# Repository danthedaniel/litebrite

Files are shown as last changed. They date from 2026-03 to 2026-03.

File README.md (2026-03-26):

# litebrite

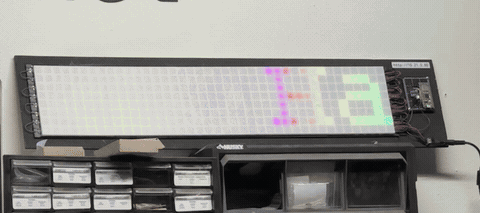
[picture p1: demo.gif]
Demo


## Hardware

- **Board**: Raspberry Pi Pico 2W (RP2350, Wi-Fi/BLE capable)
- **Display**: 40x8 WS2812B (NeoPixel) LED matrix (320 LEDs total)
- **Data pin**: GP20
- **Wiring**: Serpentine layout — even rows run right-to-left, odd rows left-to-right
- **Coordinate system**: x=0 is left, y=0 is bottom

## Firmware

The board runs **MicroPython**. All code must be compatible with MicroPython (not CPython).

Key differences from CPython:
- Use `machine.Pin`, `neopixel.NeoPixel`, `time.sleep_ms()` etc.
- No `pip` — only built-in modules and files copied to the board
- Limited RAM — keep data structures small and avoid large allocations

## Setup

```bash
# Installs type stubs for editor/IDE support
# Installs mpremote
make setup
```

Requires [uv](https://docs.astral.sh/uv/). Installs MicroPython type stubs into `typings/` for use with basedpyright/pylance, and installs `mpremote` for deploying to the board.

## Flashing MicroPython firmware

1. Hold BOOTSEL while plugging in the Pico — it mounts as a USB drive
2. Download the MicroPython `.uf2` for **Pico 2W** from https://micropython.org/download/RPI_PICO2_W/
3. Drag the `.uf2` onto the mounted drive — board reboots into MicroPython

## Deploying Code

```bash
make deploy
```

Copies all runtime files to the board and resets it.

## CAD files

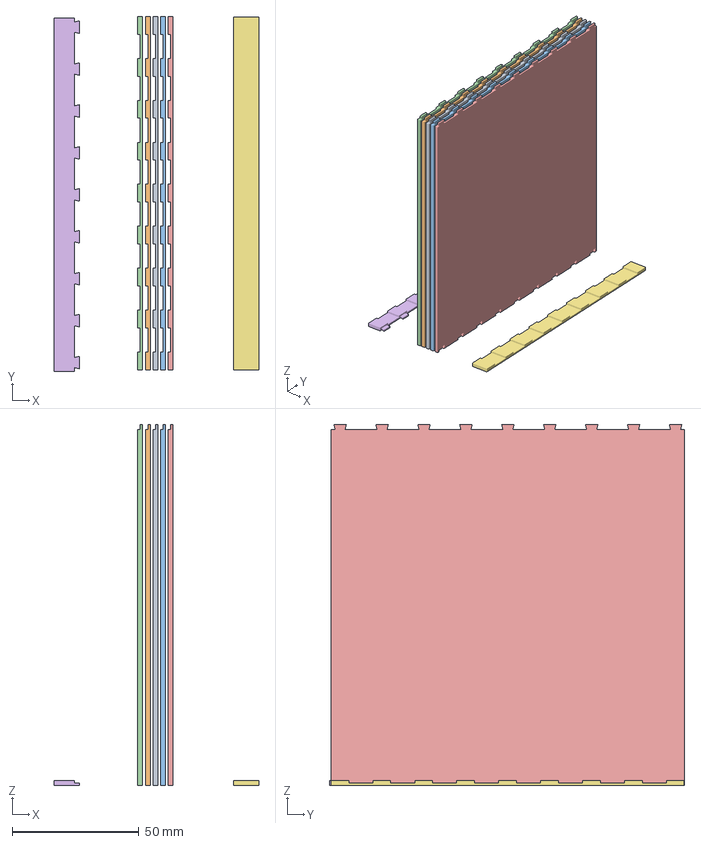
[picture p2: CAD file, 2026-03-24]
cad/led_panel.3mf
80.7 x 140.0 x 142.6 mm
led_panel.stl x 5
led_panel.stl_A
led_panel.stl_B_B

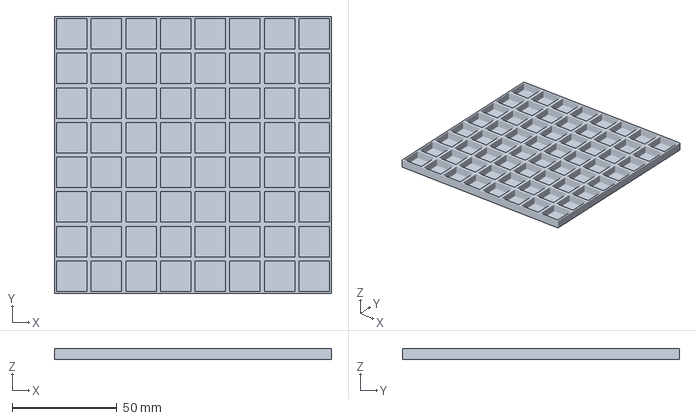
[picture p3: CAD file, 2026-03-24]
cad/led_cover.3mf
132.3 x 132.3 x 5.40 mm

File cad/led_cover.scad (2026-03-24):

overlap = 0.001;
led_size = 5;
led_spacing = 16.54;
strip_width = 10;
wall_thickness = 1;
cover_thickness = 0.4;
columns = 8;
rows = 8;

end_piece = true;

module line(row) {
    for (col = [0 : columns - 1]) {
        translate([col*led_spacing, row*led_spacing, cover_thickness])
            difference() {
                cube([led_spacing, led_spacing, 5]);
                translate([wall_thickness, wall_thickness, -overlap])
                    cube([led_spacing - 2*wall_thickness, led_spacing - 2*wall_thickness, 5 + 2*overlap]);
            };
    }
}

for (row = [0: rows - 1]) {
    difference() {
        line(row);

        if (end_piece) {
            translate([-overlap, led_spacing/2 + row*led_spacing, 8])
                rotate([0, 90, 0])
                    cylinder(1+2*overlap, 6, 6, $fn=64);
        }
    };
}

cube([columns*led_spacing, rows*led_spacing, cover_thickness+overlap]);

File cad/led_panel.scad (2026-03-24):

overlap = 0.001;
dovetail_bottom = 4;
dovetail_negative_scale = 1.02;
strip_width = 10;
led_spacing = 16.54;
panel_thickness = 2;
pixels = 8;

module dovetail(scale=1, height=panel_thickness+2*overlap) {
    length = 2 * scale;
    top = 5 * scale;
    bottom = 4 * scale;
    linear_extrude(height=height)
        polygon(points=[
            [0, 0],
            [length, (top-bottom)/2],
            [length, -(bottom + (top-bottom)/2)],
            [0, -bottom]
        ]);
}

for (i = [0 : pixels-1]) {
    translate([0, i*led_spacing, 0])
        difference() {
            cube([pixels * led_spacing, led_spacing, panel_thickness]);
            translate([-overlap, (led_spacing - strip_width + dovetail_bottom * dovetail_negative_scale) / 2, -overlap])
                dovetail(scale=dovetail_negative_scale);
        };
    
    translate([pixels * led_spacing-overlap, (led_spacing - strip_width + dovetail_bottom) / 2 + i*led_spacing, -overlap])
                dovetail(scale=1);
    
    translate([0, i*led_spacing, panel_thickness-overlap])
        cube([pixels * led_spacing, led_spacing-strip_width, panel_thickness/2]);
}

difference() {
    translate([0, pixels*led_spacing, 0])
        cube([pixels * led_spacing, led_spacing-strip_width, panel_thickness*1.5]);
    translate([-overlap, (led_spacing - strip_width + dovetail_bottom * dovetail_negative_scale) / 2 + pixels*led_spacing, -overlap])
        dovetail(scale=dovetail_negative_scale);
}

translate([pixels * led_spacing-overlap, (led_spacing - strip_width + dovetail_bottom) / 2 + pixels*led_spacing, -overlap])
    dovetail(scale=1);

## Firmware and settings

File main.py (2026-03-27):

import uasyncio
import network
import time
from font import render_text, CHAR_WIFI, CHAR_NO_WIFI
from microdot import Microdot, Request, urlencode
from screen import screen, COLS, ROWS, SCROLL_DELAY_MS
from colors import hsv_to_rgb, RGB


def rainbow_shader(x: int, _y: int, t: int) -> RGB:
    """Cycle hues across the x-axis, animated over time."""
    hue = ((x * 360) // COLS + t * 3 // 50) % 360
    return hsv_to_rgb(hue)


app = Microdot()

with open("index.html", "r") as f:
    HTML_PAGE = f.read()


@app.get('/')
async def index(_req: Request):
    return HTML_PAGE, 200, {'Content-Type': 'text/html'}


def is_hex_color(s: str) -> bool:
    return len(s) == 7 and s[0] == '#' and all(c in '0123456789abcdef' for c in s[1:])


def parse_text_payload(data: dict) -> tuple[str, bool, str]:
    text = str(data.get('text', ''))[:32]

    raw_scrolling = data.get('scrolling', False)
    if isinstance(raw_scrolling, bool):
        scrolling = raw_scrolling
    elif isinstance(raw_scrolling, str):
        scrolling = raw_scrolling.lower() == 'true'
    else:
        raise ValueError('scrolling must be a boolean or string')

    color = str(data.get('color', 'rainbow')).lower()
    if color != 'rainbow' and not is_hex_color(color):
        raise ValueError('color must be "rainbow" or a hex code like #FF0000')

    return text, scrolling, color


@app.post('/text')
async def set_text(req: Request):
    is_json = bool(req.content_type and 'application/json' in req.content_type)
    if is_json:
        data = req.json or {}
    else:
        data = req.form or {}

    try:
        text, scrolling, color = parse_text_payload(data)
    except ValueError as e:
        if is_json:
            return {'ok': False, 'error': str(e)}, 400
        else:
            return '', 303, {'Location': '/?error=' + urlencode(str(e))}

    screen.bitmap = render_text(text, "#FFFFFF" if color == "rainbow" else color)
    screen.scrolling = scrolling
    screen.shader = rainbow_shader if color == 'rainbow' else None

    if is_json:
        return {'ok': True}
    else:
        return '', 303, {'Location': '/'}


def parse_bitmap_payload(data: dict) -> list:
    raw_bitmap = data.get("bitmap")
    if not isinstance(raw_bitmap, list):
        raise ValueError('expected a list of columns')

    if len(raw_bitmap) != COLS:
        raise ValueError('bitmap must have ' + str(COLS) + ' columns')

    bitmap = []

    for x, col in enumerate(raw_bitmap):
        if not isinstance(col, list) or len(col) != ROWS:
            raise ValueError('column ' + str(x) + ' must have ' + str(ROWS) + ' pixels')

        bitmap_col = []

        for y, pixel in enumerate(col):
            if not isinstance(pixel, list) or len(pixel) != 3:
                raise ValueError('pixel at (' + str(x) + ',' + str(y) + ') must be [r, g, b]')

            for color in pixel:
                if not isinstance(color, int):
                    raise ValueError('RGB values must be integers at (' + str(x) + ',' + str(y) + ')')
                if not 0 <= color <= 255:
                    raise ValueError('RGB values must be 0-255 at (' + str(x) + ',' + str(y) + ')')

            bitmap_col.append(tuple(pixel))

        bitmap.append(bitmap_col)

    return bitmap


@app.post('/bitmap')
async def set_bitmap(req: Request):
    data = req.json or {}

    try:
        bitmap = parse_bitmap_payload(data)
    except ValueError as e:
        return {'ok': False, 'error': str(e)}, 400

    screen.bitmap = bitmap
    screen.scrolling = False
    screen.shader = None

    return {'ok': True}


async def display_loop() -> None:
    while True:
        screen.update()
        await uasyncio.sleep_ms(SCROLL_DELAY_MS)


def connect_wifi() -> str:
    wlan = network.WLAN(network.STA_IF)
    wlan.active(True)
    wlan.connect("Noisebridge", "noisebridge")
    dots = ["...", "..", ".", ".."]

    max_wait = 20
    while max_wait > 0:
        screen.show_text(CHAR_WIFI + " " + dots[max_wait % len(dots)])

        status = wlan.status()
        if status == network.STAT_GOT_IP:
            break
        if status < 0:
            screen.show_text(CHAR_NO_WIFI + " fail")
            raise RuntimeError("WiFi connection failed, status=" + str(status))

        max_wait -= 1
        time.sleep(1)

    if not wlan.isconnected():
        screen.show_text(CHAR_NO_WIFI + " fail")
        raise RuntimeError("WiFi connection timed out")

    ip = str(wlan.ifconfig()[0])
    screen.show_text(CHAR_WIFI + " :D")
    time.sleep(2)

    return ip


def main() -> None:
    screen.clear()
    ip = connect_wifi()

    bitmap = render_text(ip, "#FFFFFF")
    screen.bitmap = bitmap
    screen.scrolling = len(bitmap) > COLS

    uasyncio.create_task(display_loop())
    app.run(port=80)


def show_error(e: Exception) -> None:
    screen.bitmap = render_text("Error: " + str(e)[0:64], "#FF0000")
    screen.scrolling = True

    while True:
        screen.update()
        time.sleep_ms(SCROLL_DELAY_MS)


try:
    main()
except Exception as e:
    show_error(e)

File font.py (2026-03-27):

from colors import Bitmap, hex_to_rgb

CHAR_WIFI = '\x01'
CHAR_NO_WIFI = '\x02'

FONT = {
    ' ': [
        [0,0,0],
        [0,0,0],
        [0,0,0],
        [0,0,0],
        [0,0,0],
        [0,0,0],
        [0,0,0],
        [0,0,0],
    ],
    'A': [
        [0,0,0,1,1,0,0],
        [0,0,1,0,0,1,0],
        [0,1,0,0,0,1,0],
        [0,1,0,0,0,1,0],
        [0,1,1,1,1,1,0],
        [0,1,0,0,0,1,0],
        [1,1,1,0,1,1,1],
        [0,0,0,0,0,0,0],
    ],
    'B': [
        [1,1,1,1,0],
        [0,1,0,0,1],
        [0,1,0,0,1],
        [0,1,1,1,0],
        [0,1,0,0,1],
        [0,1,0,0,1],
        [1,1,1,1,0],
        [0,0,0,0,0],
    ],
    'C': [
        [0,0,1,1,0],
        [0,1,0,0,1],
        [1,0,0,0,1],
        [1,0,0,0,0],
        [1,0,0,0,0],
        [1,0,0,0,1],
        [0,1,1,1,0],
        [0,0,0,0,0],
    ],
    'D': [
        [1,1,1,1,0,0],
        [0,1,0,0,1,0],
        [0,1,0,0,0,1],
        [0,1,0,0,0,1],
        [0,1,0,0,0,1],
        [0,1,0,0,1,0],
        [1,1,1,1,0,0],
        [0,0,0,0,0,0],
    ],
    'E': [
        [1,1,1,1,1,1],
        [0,1,0,0,0,1],
        [0,1,0,0,0,1],
        [0,1,1,1,0,0],
        [0,1,0,0,0,0],
        [0,1,0,0,0,1],
        [1,1,1,1,1,1],
        [0,0,0,0,0,0],
    ],
    'F': [
        [1,1,1,1,1,1],
        [0,1,0,0,0,1],
        [0,1,0,0,0,1],
        [0,1,1,1,0,0],
        [0,1,0,0,0,0],
        [0,1,0,0,0,0],
        [1,1,1,0,0,0],
        [0,0,0,0,0,0],
    ],
    'G': [
        [0,0,1,1,0,0,0],
        [0,1,0,0,1,0,0],
        [1,0,0,0,0,0,0],
        [1,0,0,1,1,1,1],
        [1,0,0,0,0,1,0],
        [0,1,0,0,0,1,0],
        [0,0,1,1,1,0,0],
        [0,0,0,0,0,0,0],
    ],
    'H': [
        [1,1,1,0,1,1,1],
        [0,1,0,0,0,1,0],
        [0,1,0,0,0,1,0],
        [0,1,1,1,1,1,0],
        [0,1,0,0,0,1,0],
        [0,1,0,0,0,1,0],
        [1,1,1,0,1,1,1],
        [0,0,0,0,0,0,0],
    ],
    'I': [
        [1,1,1],
        [0,1,0],
        [0,1,0],
        [0,1,0],
        [0,1,0],
        [0,1,0],
        [1,1,1],
        [0,0,0],
    ],
    'J': [
        [0,0,0,1,1,1],
        [0,0,0,0,1,0],
        [0,0,0,0,1,0],
        [0,1,0,0,1,0],
        [1,0,0,0,1,0],
        [1,0,0,0,1,0],
        [0,1,1,1,0,0],
        [0,0,0,0,0,0],
    ],
    'K': [
        [1,1,1,0,1,1,1],
        [0,1,0,0,0,1,0],
        [0,1,0,0,1,0,0],
        [0,1,1,1,0,0,0],
        [0,1,0,0,1,0,0],
        [0,1,0,0,0,1,0],
        [1,1,1,0,1,1,1],
        [0,0,0,0,0,0,0],
    ],
    'L': [
        [1,1,1,0,0,0],
        [0,1,0,0,0,0],
        [0,1,0,0,0,0],
        [0,1,0,0,0,0],
        [0,1,0,0,0,1],
        [0,1,0,0,0,1],
        [1,1,1,1,1,1],
        [0,0,0,0,0,0],
    ],
    'M': [
        [1,1,0,0,0,0,0,1,1],
        [0,1,1,0,0,0,1,1,0],
        [0,1,0,1,0,1,0,1,0],
        [0,1,0,0,1,0,0,1,0],
        [0,1,0,0,1,0,0,1,0],
        [0,1,0,0,0,0,0,1,0],
        [1,1,1,0,0,0,1,1,1],
        [0,0,0,0,0,0,0,0,0],
    ],
    'N': [
        [1,1,0,0,1,1,1],
        [0,1,0,0,0,1,0],
        [0,1,1,0,0,1,0],
        [0,1,0,1,0,1,0],
        [0,1,0,0,1,1,0],
        [0,1,0,0,0,1,0],
        [1,1,1,0,0,1,1],
        [0,0,0,0,0,0,0],
    ],
    'O': [
        [0,0,1,1,1,0],
        [0,1,0,0,0,1],
        [1,0,0,0,0,1],
        [1,0,0,0,0,1],
        [1,0,0,0,0,1],
        [1,0,0,0,1,0],
        [0,1,1,1,0,0],
        [0,0,0,0,0,0],
    ],
    'P': [
        [1,1,1,1,1,0],
        [0,1,0,0,0,1],
        [0,1,0,0,0,1],
        [0,1,0,0,0,1],
        [0,1,1,1,1,0],
        [0,1,0,0,0,0],
        [1,1,1,0,0,0],
        [0,0,0,0,0,0],
    ],
    'Q': [
        [0,0,1,1,0,0],
        [0,1,0,0,1,0],
        [1,0,0,0,0,1],
        [1,0,0,0,0,1],
        [1,0,0,1,0,1],
        [1,0,0,0,1,0],
        [0,1,1,1,0,1],
        [0,0,0,0,0,0],
    ],
    'R': [
        [1,1,1,1,1,0,0],
        [0,1,0,0,0,1,0],
        [0,1,0,0,0,1,0],
        [0,1,1,1,1,0,0],
        [0,1,0,0,1,0,0],
        [0,1,0,0,0,1,0],
        [1,1,1,0,1,1,1],
        [0,0,0,0,0,0,0],
    ],
    'S': [
        [0,0,1,1,1,0],
        [0,1,0,0,0,1],
        [0,1,0,0,0,1],
        [0,0,1,1,0,0],
        [1,0,0,0,1,0],
        [1,0,0,0,0,1],
        [0,1,1,1,1,0],
        [0,0,0,0,0,0],
    ],
    'T': [
        [1,1,1,1,1,1,1],
        [1,0,0,1,0,0,1],
        [1,0,0,1,0,0,1],
        [0,0,0,1,0,0,0],
        [0,0,0,1,0,0,0],
        [0,0,0,1,0,0,0],
        [0,0,1,1,1,0,0],
        [0,0,0,0,0,0,0],
    ],
    'U': [
        [1,1,1,0,1,1,1],
        [0,1,0,0,0,1,0],
        [0,1,0,0,0,1,0],
        [0,1,0,0,0,1,0],
        [0,1,0,0,0,1,0],
        [0,1,0,0,0,1,0],
        [0,0,1,1,1,0,0],
        [0,0,0,0,0,0,0],
    ],
    'V': [
        [1,1,1,0,1,1,1],
        [0,1,0,0,0,1,0],
        [0,1,0,0,0,1,0],
        [0,0,1,0,1,0,0],
        [0,0,1,0,1,0,0],
        [0,0,0,1,0,0,0],
        [0,0,0,1,0,0,0],
        [0,0,0,0,0,0,0],
    ],
    'W': [
        [1,1,1,0,0,0,1,1,1],
        [0,1,0,0,1,0,0,1,0],
        [0,1,0,0,1,0,0,1,0],
        [0,1,0,0,1,0,0,1,0],
        [0,1,0,0,1,0,0,1,0],
        [0,1,0,0,1,0,0,1,0],
        [0,0,1,1,0,1,1,0,0],
        [0,0,0,0,0,0,0,0,0],
    ],
    'X': [
        [1,1,1,0,1,1,1],
        [0,1,0,0,0,1,0],
        [0,0,1,0,1,0,0],
        [0,0,0,1,0,0,0],
        [0,0,1,0,1,0,0],
        [0,1,0,0,0,1,0],
        [1,1,1,0,1,1,1],
        [0,0,0,0,0,0,0],
    ],
    'Y': [
        [1,1,1,0,1,1,1],
        [0,1,0,0,0,1,0],
        [0,1,0,0,0,1,0],
        [0,0,1,0,1,0,0],
        [0,0,0,1,0,0,0],
        [0,0,0,1,0,0,0],
        [0,0,1,1,1,0,0],
        [0,0,0,0,0,0,0],
    ],
    'Z': [
        [1,1,1,1,1],
        [1,0,0,0,1],
        [0,0,0,1,0],
        [0,0,1,0,0],
        [0,1,0,0,0],
        [1,0,0,0,1],
        [1,1,1,1,1],
        [0,0,0,0,0],
    ],
    'a': [
        [0,0,0,0,0,0],
        [0,1,1,1,0,0],
        [0,0,0,0,1,0],
        [0,1,1,1,1,0],
        [1,0,0,0,1,0],
        [1,0,0,0,1,0],
        [0,1,1,1,1,1],
        [0,0,0,0,0,0],
    ],
    'b': [
        [1,1,0,0,0,0],
        [0,1,0,0,0,0],
        [0,1,1,1,0,0],
        [0,1,0,0,1,0],
        [0,1,0,0,0,1],
        [0,1,0,0,0,1],
        [1,1,1,1,1,0],
        [0,0,0,0,0,0],
    ],
    'c': [
        [0,0,0,0,0],
        [0,1,1,0,0],
        [1,0,0,1,0],
        [1,0,0,0,0],
        [1,0,0,0,0],
        [1,0,0,0,1],
        [0,1,1,1,0],
        [0,0,0,0,0],
    ],
    'd': [
        [0,0,0,0,1,1],
        [0,0,0,0,1,0],
        [0,0,1,1,1,0],
        [0,1,0,0,1,0],
        [1,0,0,0,1,0],
        [1,0,0,0,1,0],
        [0,1,1,1,1,1],
        [0,0,0,0,0,0],
    ],
    'e': [
        [0,0,0,0,0,0],
        [0,0,1,1,0,0],
        [0,1,0,0,1,0],
        [1,0,0,0,1,0],
        [1,1,1,1,0,0],
        [1,0,0,0,0,1],
        [0,1,1,1,1,0],
        [0,0,0,0,0,0],
    ],
    'f': [
        [0,0,0,1,1,1],
        [0,0,1,0,0,0],
        [1,1,1,1,1,0],
        [0,0,1,0,0,0],
        [0,0,1,0,0,0],
        [0,0,1,0,0,0],
        [0,1,1,1,0,0],
        [0,0,0,0,0,0],
    ],
    'g': [
        [0,0,0,0,0],
        [0,0,1,1,1],
        [0,1,0,0,1],
        [1,0,0,0,1],
        [1,0,0,0,1],
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
